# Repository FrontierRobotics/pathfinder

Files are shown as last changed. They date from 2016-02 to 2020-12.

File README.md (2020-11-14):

# Pathfinder

This is the main repository for the Pathfinder Rover. You're in the right spot for over-arching documentation and project tracking. This is also where we keep files and source code central to the design.

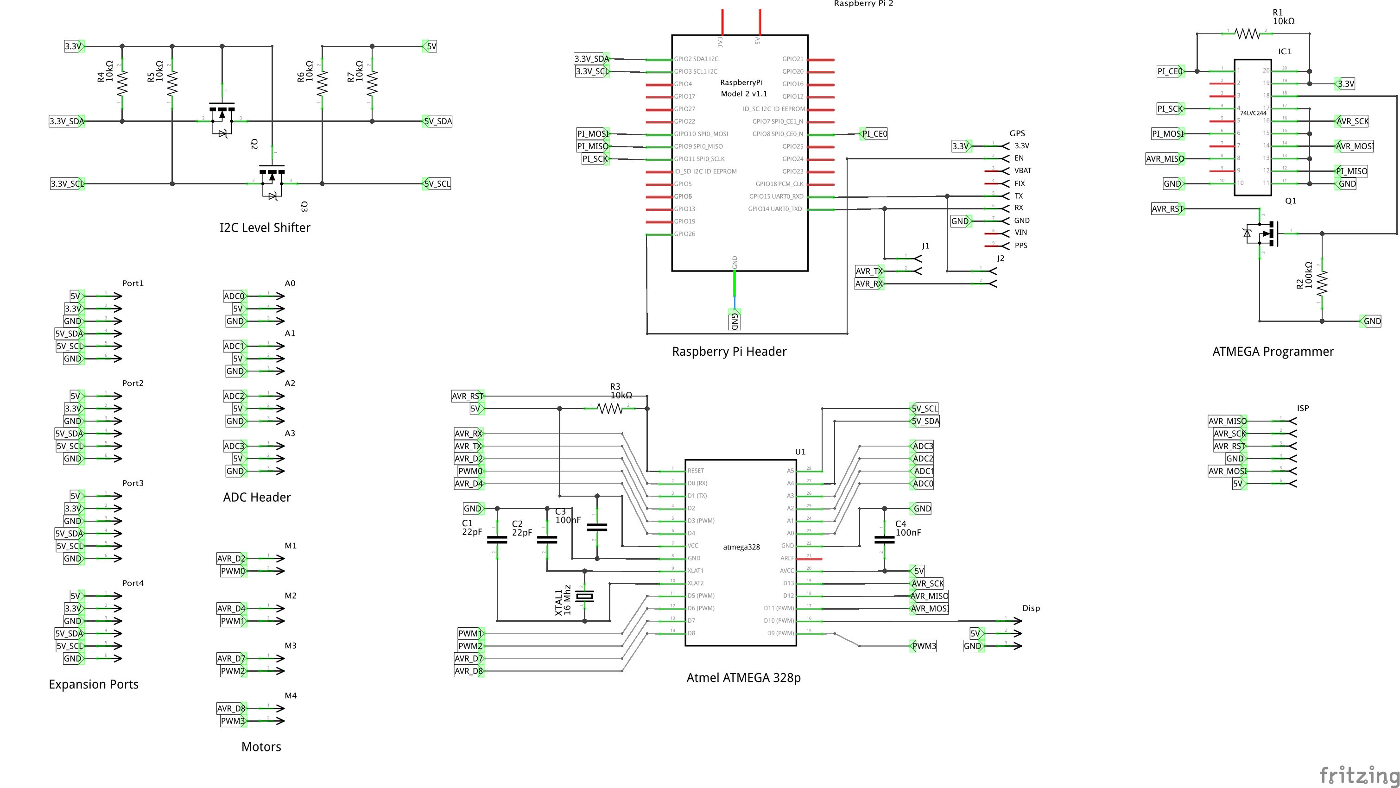
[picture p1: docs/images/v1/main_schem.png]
mainboard


## Roadmap

See our [release roadmap](https://github.com/FrontierRobotics/pathfinder/milestones) to learn about upcoming plans.

## Documentation

Inital Setup:

* [Raspberry Pi Setup](docs/rpi_setup.md)
* [Atmel Programmer Setup](docs/atmel_programmer_setup.md)
* [GPS Setup](docs/gps_setup.md)

Mainboard Circuits:

* [Power Supply](docs/mainboard_power_supply.md)
* [Power Monitor](docs/mainboard_power_monitor.md)

Arduino Code:

* [Protocol](docs/i2c_protocol.md)
* [Development](docs/arduino_build.md)

Raspberry Pi Code:

* [Protocol](docs/i2c_protocol.md)
* [Development](docs/rpi_build.md)

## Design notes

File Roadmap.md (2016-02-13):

# Roadmap

Names: WALL-E, CondonExplorationAdminsration: Pathfinder, Popcorn, Voyager, Snowman, Hubble, CondonExplorationVehichle, TCs, T3R, R2C2

Milestone | Important Considerations
---- | ------------------------
Navigation | Basic chassis, motor control, and obstacle avoidance
Home Waypoints | Position and direction, refined motor control and obstacle avoidance
Park Waypoints | All terrain chassis, advanced motor control and obstacle avoidance
Get to Park | Computer vision and high visibility for traffic avoidance, 
Home Samples | Sampling hardware
Park Samples | Sampling on longer missions
Natural Area Samples | Harsh terrain

## Navigation

* Avoid obstacles (Man Made)
  * Computer vision *(D: 12, P: )*
  * Rangefinding *(D: 5, P: )*
  * LIDAR *(D: W, P: )*
* Direction *(D: 1, P: )*
* Position *(D: 2, P: )*
* Tracking progress on path *(D: 2, P: )*
* Following a known path using waypoints *(D: 5, P: )*
* Motor control *(D: 3, P: )*

## Fail Safe Plan (Recovery)

* Return to known spot *(D: 8, P: )*
* Transmit location *(D: 3, P: )*
* Sticker advertising a fine *(D: 1, P: )*

## Defense

* Plant itself into the earth *(D: 12, P: )*
* Self destruct *(D: 5, P: )*
* Hard armor *(D: 8, P: )*
* Spikes *(D: , P: )*
* Auto-camoflage *(D: , P: )*
* Shock *(D: , P: )*
* Gas (pepper spray or stinky) *(D: , P: )*
* Flashing Lights *(D: , P: )*

## Weather Proofing

* Rain *(D: , P: )*
* Snow *(D: , P: )*

## Harsh Terrain

* Cliffs *(D: , P: )*
* Tall Grass *(D: , P: )*
* Rough Rocks *(D: , P: )*
* Water *(D: , P: )*
  * Puddle *(D: , P: )*
  * Streams *(D: , P: )*
  * Ponds *(D: , P: )*
  * Lakes *(D: , P: )*
  * Rivers *(D: , P: )*
  * Oceans *(D: , P: )*
* Getting stuck
  * Spikes *(D: , P: )*
  * Transmit SOS *(D: , P: )*

## Travel Long Distances

* Energy
  * Solar power *(D: , P: )*
  * Intelligent standby that takes advantage of best sun *(D: , P: )*
  * Large batteries *(D: , P: )*
  * Wind *(D: , P: )*
  * Fuel Cell *(D: , P: )*
* Communication
  * WiFi *(D: , P: )*
  * SatComm *(D: , P: )*
  * Cellular *(D: , P: )*

## Taking Samples

* Dirt samples
  * Claw *(D: , P: )*
  * rotor scoop *(D: , P: )*
* Rock samples
  * Pick up small rocks *(D: , P: )*
  * Drill into large rocks *(D: , P: )*
* Water samples *(D: , P: )*
* Air samples *(D: , P: )*
* Pictures *(D: , P: )*
* Sound *(D: , P: )*
* Audio *(D: , P: )*
* Weather
  * Tempurature *(D: , P: )*
  * Light *(D: , P: )*
  * Pressure *(D: , P: )*
  * Humidity *(D: , P: )*
* Life
  * Snails *(D: , P: )*
  * Plants *(D: , P: )*
  * Microbes *(D: , P: )*
  * Crickets (call them in) *(D: , P: )*
  * Mice *(D: , P: )*

## Sample Analysis

* Spectrometer *(D: , P: )*

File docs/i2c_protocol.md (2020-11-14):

I2C Protocol
============

I2C Device Address: `0x1A`

To initiate an action or send a command to an attached device, the first byte
must be the internal address for that action. Each action has a unique command
sequence described in the sections below.

The general form for sending commands follows:

| Byte 0 | Byte 1  | Following Bytes... |
| --- | --- | --- |
| Internal Address | Command | Command Parameters |

The available actions and their internal address:

| Action  | Internal Addr |
| --- | --- |
| LCD | `0x00` |
| Motor 1 | `0x01` |
| Motor 2 | `0x02` |
| Status  | `0x10` |

LCD
---

**_Not Implemented_** - not necessary, and somewhat unsafe to transmit arbitrary message lengths.

The second byte in the transmission (Byte 1) specifies the command for the LCD.

| Command | Byte 1 | Parameters |
| --- | --- | --- |
| Write | `0x00` | 20 or less bytes to print |
| Set Cursor | `0x01` | byte: row, byte: column |
| Set Brightness | `0x02` | byte: level |
| Clear | `0x02` | None |

Motor
-----

The second byte in the transmission (Byte 1) specifies the command for the
Motor.

| Command | Byte 1 | Parameters |
| --- | --- | --- |
| Forward | `0x00` | byte: speed, `0x00` for stop |
| Reverse | `0x01` | byte: speed, `0x00` for stop |

Status
------

A status message is sent to the master with every interaction. It is possible
to receive a dedicated status message as well.

The form of the status message is a 1 byte value for each sensor.

| | Byte 0 | Byte 1 | Byte 2 |
| --- | --- | --- | --- |
| Sensor | IR 1 | IR 2 | IR 3 |

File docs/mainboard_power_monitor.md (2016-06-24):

# Mainboard Power Monitor

The power monitor for the mainboard is designed with the following features:

* Safe shutdown sequence commands to Raspberry Pi.
* Shutdown interface to mainboard power supply.
* Power quality monitoring and low-voltage protection.
* Health feedback data over I2C.
* Operation mode indicator LED.

## Circuit Overview

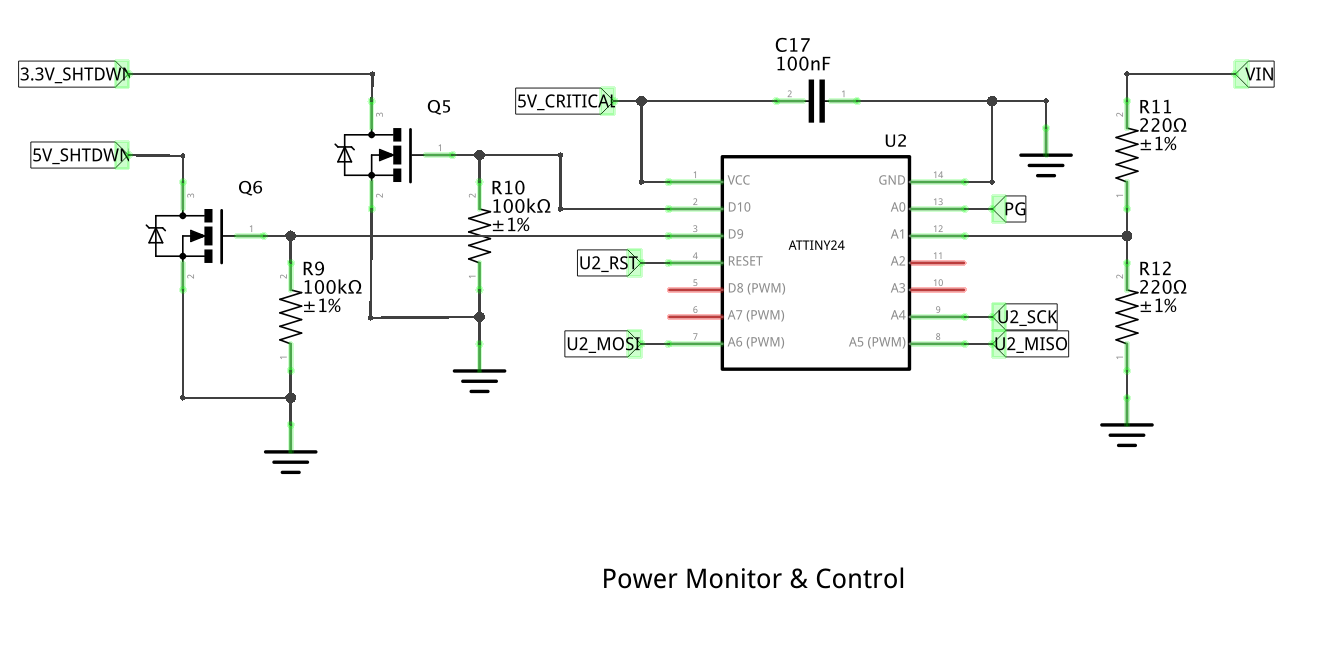
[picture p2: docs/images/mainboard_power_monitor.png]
Circuit Diagram


## Bill of Materials

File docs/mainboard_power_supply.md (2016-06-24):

# Mainboard Power Supply

The power supply for the mainboard is designed with the following features:

* Wide voltage input range of 5.4V to 36V.
* Selectively disabled 2A, 5V and 1A, 3.3V power buses.
* Always-On 1A, 5V critical power bus.

## Circuit Overview

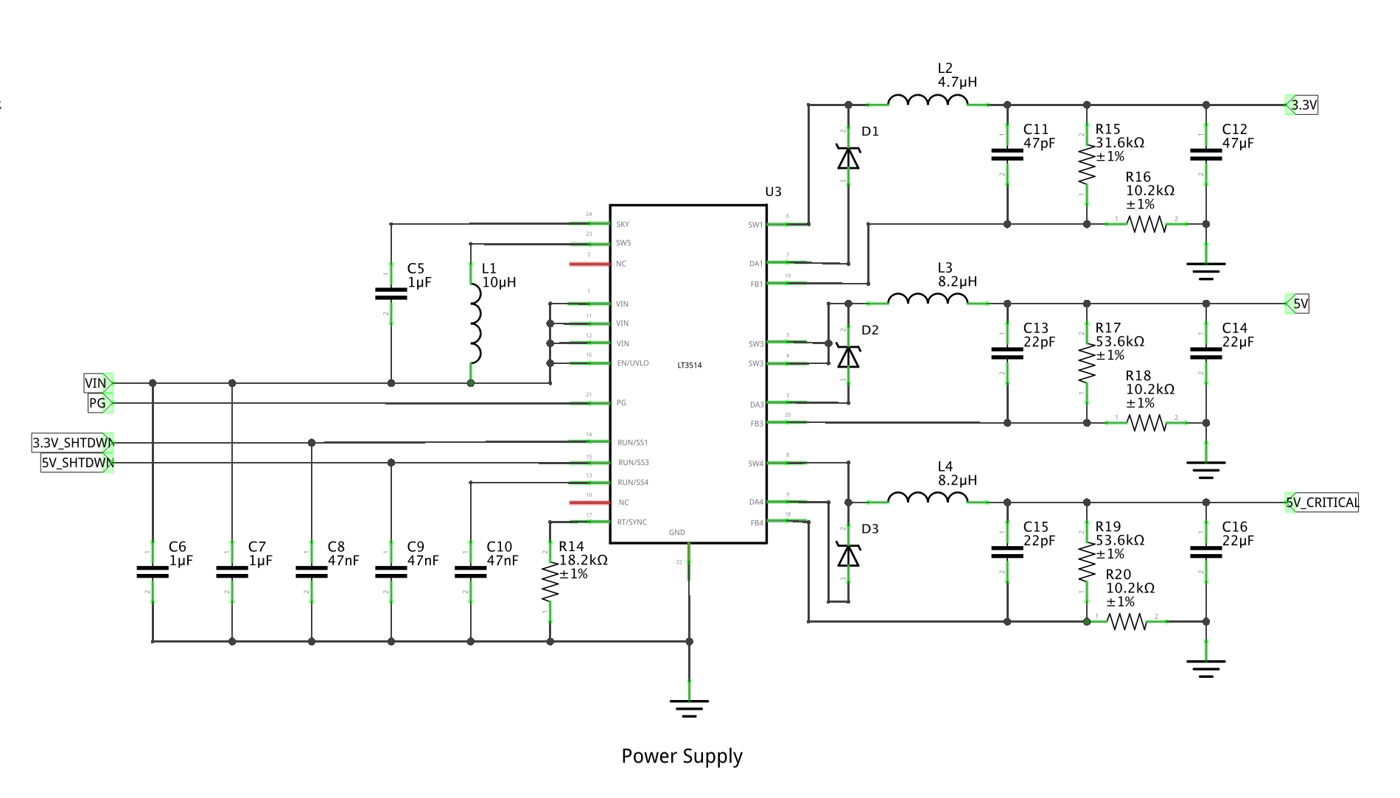
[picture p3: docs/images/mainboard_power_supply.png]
Circuit Diagram


The heart of the power supply is the LT3514 Triple Step-Down Switching Regulator. It consists of three buck regulators with a single 2A channel, and two 1A channels. The device is capable of accepting voltages from 3.2V up to 36V. An on-chip boost regulator allows each channel to operate up to 100% duty cycle, minimizing the need for leveling circuitry.

The LT3514 operates robustly in fault conditions. Cycle-by-cycle peak current limit and catch diode current limit sensing protect the IC, and other mainboard components during overload conditions. Thermal shutdown protects the internal power switches at elevated temperatures. Soft-start helps control the peak inductor current during startup.

The LT3514 features output voltage tracking and sequencing, programmable frequency, programmable undervoltage lockout, and a power good pin to indicate when all ouputs are in regulation.

Channel 3 has the highest current rating, and thus will be used to supply the Raspberry Pi and 5V bus. Channel 1, at 1A, will supply the 3.3V bus. Channel 4 will supply the 5V critical bus for the mainboard power monitor. Channels 1 and 3 will be selectively disabled by the mainboard power monitor circuit during shutdown or low power scenarios. Channel 4 will always be on, supplying the power monitor in standby. By that nature, EN/UVLO will always be enabled as well to ensure constant operation.

## FB Resistor Network

The general formula for the FB resistor network is:

```
R1 = R2 * ((Vout/0.8V) - 1)
```

The datasheet states to use 1% tolerance resisitors, and that a good value for R2 is 10.2kΩ. R2 should not exceed 20kΩ to avoid bias current error.

therefore:

```
Channel 1: 1A, 3.3V
R1 = 10.2kΩ * ((3.3V/0.8V - 1) = 31875Ω ≅ 31.6kΩ

Channel 3: 2A, 5V
R1 = 10.2kΩ * ((5V/0.8V - 1) = 53550Ω ≅ 53.6kΩ

Channel 4: 1A, 5V
R1 = 10.2kΩ * [(5V/0.8V) - 1] = 53550Ω ≅ 53.6kΩ
```
conclusion:

```
R16,18,20 = 10.2kΩ @ ±1%
R15       = 31.6kΩ @ ±1%
R17,19    = 53.6kΩ @ ±1%
```

## Input Voltage Range

The minimum input voltage to regulate the output generally has to be at least 400mV greater than the greatest programmed output voltage. The only exception is when the largest output is less than 2.8V in which case the minimum is 3.2V

The absolute maximum input voltage is 40V, and the LT3514 will regulate so long as the voltage remains less than or equal to that value. However, for constant frequency operation the maximum input voltage is determined through the following formula:

```
VIN(PS) = [(VOUT + VD)/(fSW * tON(MIN)] + VSW - VD
```

where:

* `VIN(PS)` is the maximum input voltage to operate in constant frequency operation without skipping pulses.
* `VOUT` is the programmed output voltage.
* `VSW` is the switch voltage drop, at `IOUT1,4 = 1A`, `VSW1,4 = 0.4V`, at `IOUT3 = 2A`, `VSW3 = 0.4V`.
* `VD` is the catch diode forward voltage drop, for an appropriately sized diode, `VD = 0.4V`.
* `fSW` is the programmed switching frequency. As will be shown in the next section, `fSW = 1.0 MHz`.
* `tON(MIN)` is the minimum on-time, worst-case over temperature = 110ns (at T = 125ºC).

therefore:

```
VIN(PS) = [(5V + 0.4V)/(1.0 MHz * 110ns)] + 0.4V - 0.4V = 49.091V = 40V (device maximum)
VIN(PS) = [(3.3V + 0.4V)/(1.0 MHz * 110ns)] + 0.4V - 0.4V = 40.7V = 40V (device maximum)
```

conclusion:

Our computed `VIN(PS) = 40.7V` exceeds the maximum of 40V, and thus 40V shall be the upper value of VIN. However, the datasheet recommends not starting the LT3514 at input voltages greater than 36V, as the LT3514 must simultaneously conduct maximum currents at high VIN.

Therefore, the recommended input voltage range is `5.4V < VIN < 36V`.

## Frequency Selection

There are two ways to program the frequency:

* Tying a 1% tolerance resistor `RT` from the `RT/SYNC` pin to ground.
* Synchronize the internal oscillator to an external clock.

For our power supply, we'll use the first method. The 1.0 MHz frequency choosen is in the midrange of the LT3514's 250kHz to 2.5MHz operating range. In addition, as shown above, 1.0 MHz results in a full-range `VIN(PS)`. The datasheet includes a table for choosing the proper resistor value for different frequencies.

conclusion:

```
fSW = 1.0 MHz
RT = 18.2kΩ @ ±1%
```

## BOOST Regulator and SKY Pin Considerations

The on-chip boost regulator generates the SKY voltage to be 4.85V above VIN. The SKY voltage is the source of the drive current for the buck regulators that drive the output channels. A good choice for the inductor that will ensure each buck regulator will have sufficient drive current is given by:

```
L = 20.5µH / f
```

where `f` is in MHz. This gives a value of `L = 20.5µH` for `f = 1.0 MHz`.

The optimal SKY pin output current requirement and inductor value is calculated by:

```
ISKY = (IOUT1 * VOUT1 + IOUT3 * VOUT3 + IOUT4 * VOUT4) / 50 * VIN

L = VIN * DC5 / 2 * fSW * [0.3 * (1 - 0.25 * DC5) - ISKY]
```

where:

* `fSW = 1.0 MHz` is the programmed switching frequency.
* `VIN = 12V`, which will be a typical value.
* `DC5 = 0.29412` is the boost regulator duty cycle, given by: `DC5 = 5V/(VIN + 5V)`.
* `VOUT3,4 = 5V`, `VOUT1 = 3.3V`, `IOUT1,4 = 1A`, `IOUT3 = 2A`

therefore:

```
ISKY = (1A * 3.3V + 2A * 5V + 1A * 5V) / 50 * 12
ISKY = 18.3 / 600 = 30.5mA

L = 12V * 0.29412 / 2 * 1.0 MHz * [0.3 * (1 - 0.25 * 0.29412) - 30.5mA]
L = 3.52944 / 2000000 * (0.3 * 0.92647 - 0.0305)
L = 3.52944 / 2000000 * 0.247441 = 0.00000713188194H
L ≅ 7.1µH
```

From the example in the datasheet using different output voltages, we calculated this optimal value of L:

```
ISKY = 13.4 / 600 = 22.3mA
L ≅ 6.9µH
```

This is very close to our computed value. The value of L chosen for the example is 10µH. We will also use this value for our design.

conclusion:

The chosen value of the inductor is 10µH for `VIN = 12V`.

## Inductor Selection

```
L = 2 * (VOUT + VD)/fSW for Channels 1, 4
L = (VOUT + VD)/fSW for Channel 3
```

## Bill of Materials

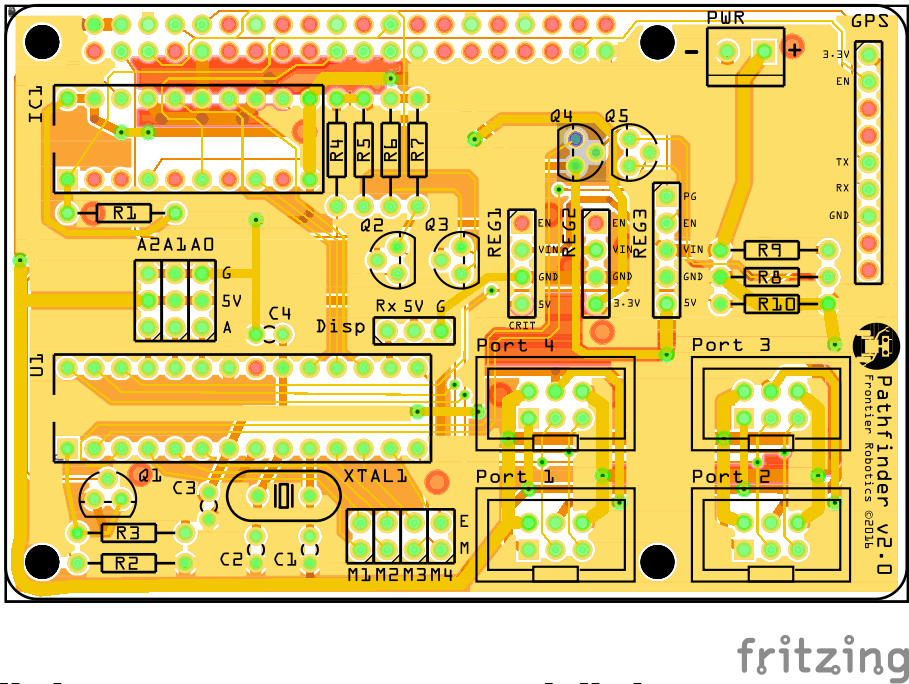
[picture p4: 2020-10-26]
docs/images/v2/main_pcb.png

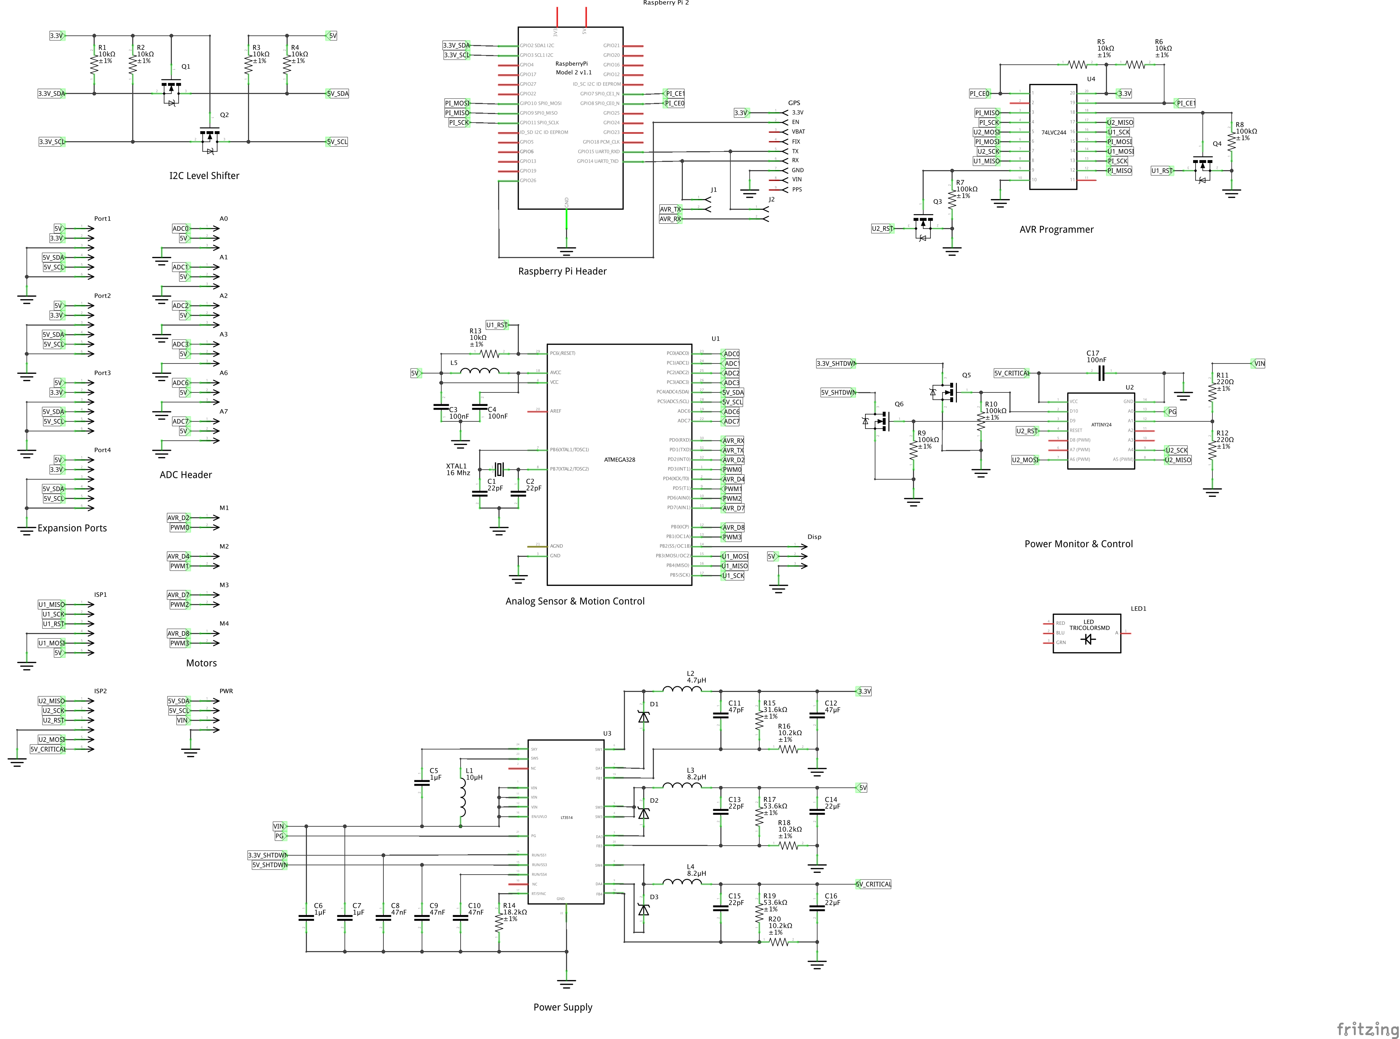
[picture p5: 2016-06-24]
docs/images/mainboard.png

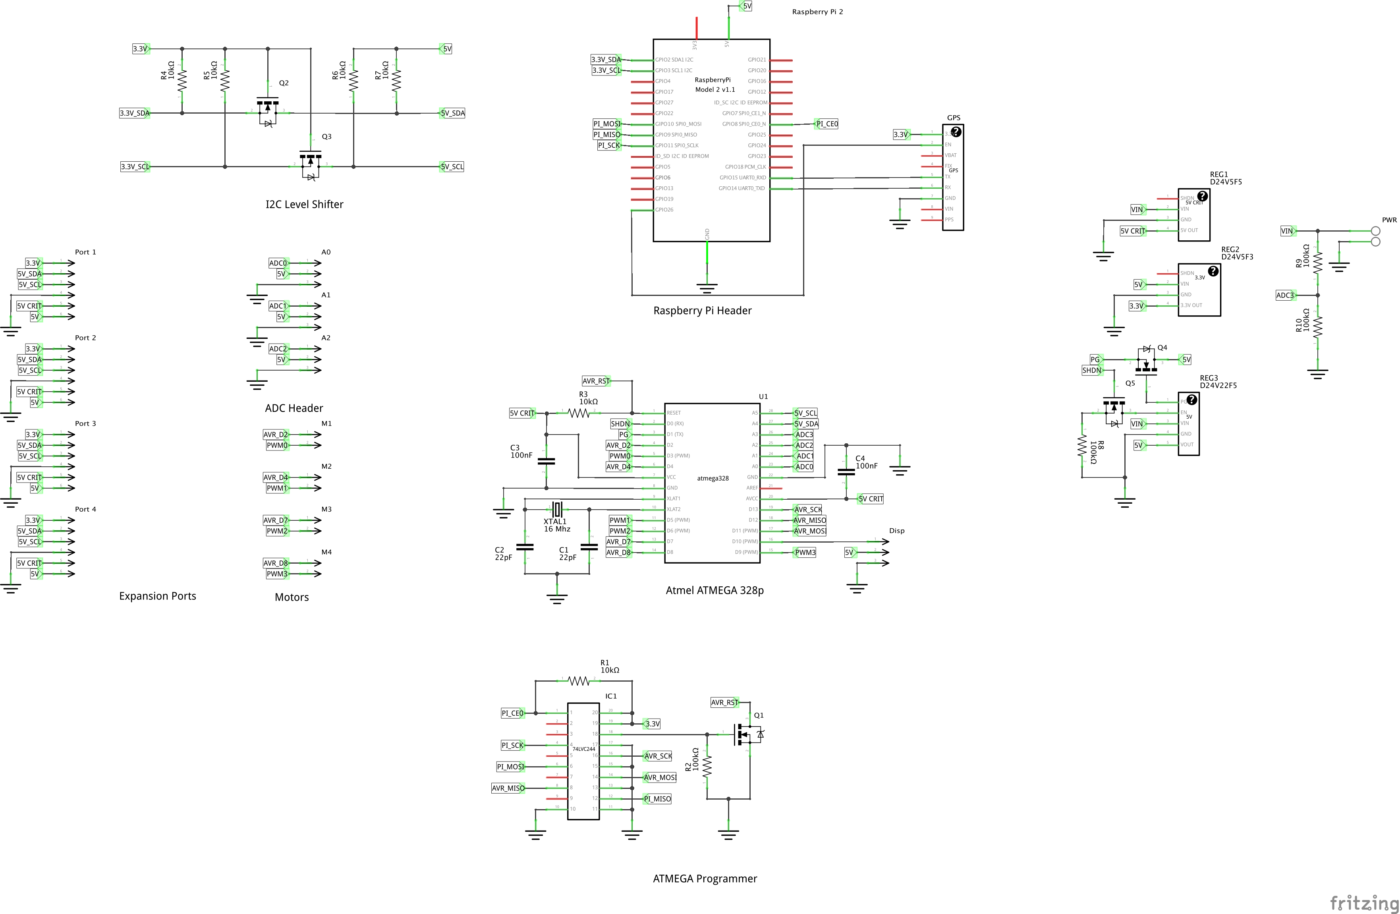
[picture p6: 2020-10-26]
docs/images/v2/main_schem.png

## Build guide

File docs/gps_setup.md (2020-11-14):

# GPS Setup

Pathfinder uses the [Ultimate GPS module from Adafruit](https://www.adafruit.com/product/746).

## Stealing back the serial port from the console

In addition to enabling the serial port like we did in [Raspberry Pi Setup](rpi_setup.md), we also have to take it away from the console service.

```
sudo systemctl stop serial-getty@ttyS0.service
sudo systemctl disable serial-getty@ttyS0.service
```

You also need to remove the console from the cmdline.txt. If you edit this with:

```
sudo nano /boot/cmdline.txt
```

You will see something like:

```
dwc_otg.lpm_enable=0 console=serial0,115200 console=tty1 root=/dev/mmcblk0p2 rootfstype=ext4 elevator=deadline fsck.repair=yes root wait
```

Remove the part mapping the console to serial0:

```
console=serial0,115200
```

Save and reboot for changes to take effect.

## Observing the output

The Ultimate GPS module runs at 9600 baud 8N1.

### Minicom

If this is your thing, first start it up in setup mode:

```
sudo minicom -s
```

Put in the proper device, `/dev/ttyS0` and the baud rate, then start it up like normal:

```
sudo minicom
```

### Screen

This is probably the easiest.

```
sudo screen /dev/ttyS0 9600
```

That's it! [See the rest of the documentation to continue.](../README.md)

----

* [Using UART](https://learn.adafruit.com/adafruit-ultimate-gps-on-the-raspberry-pi/using-uart-instead-of-usb)
* [Configuring GPIO Serial](http://spellfoundry.com/2016/05/29/configuring-gpio-serial-port-raspbian-jessie-including-pi-3)

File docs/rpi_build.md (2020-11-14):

Raspberry Pi Build
==================

Cross Compiling
---------------

Change directories to where `main.go` resides and run `go build` with environment variables for the target platform:
```
$ cd cmd/pathfinder
$ env GOOS=linux GOARCH=arm GOARM=5 go build
```

Send the compiled binary to the Raspberry Pi:
```
$ scp pathfinder pi@192.168.3.147:/home/pi
```

Executing
---------

First make sure the Arduino code is [built and flashed](arduino_build.md).

On the Raspberry Pi:

Run the executable to start upPathfinder:

```
$ ./pathfinder
```

Or, to test the I2C commands directly...

Make both motors go forward at 50%:
```
$ ./test-i2c 010180 // Motor 1
$ ./test-i2c 020180 // Motor 2
```

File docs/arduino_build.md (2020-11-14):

Arduino Build
=============

Wiring
------

**NOTE!** When connecting and referencing pins, use the Arduino pin number! For example, use pin 2 a.k.a D2 in code
instead of physical pin 4.

Compilation
-----------

From the root of this repository, open [Main.ino](../arduino/Main/Main.ino)

Click the Arduino/Verify button at the top right. (Opt+Cmd+R)

The output of the compilation goes into the [build directory](../arduino/Main/build)(ignored in Git). Inside this directory you'll find two `.hex` files, with and without the bootloader. We can use usually the one without the bootloader because it's already in flash.

Send the compiled `.hex` to the Raspberry pi for flashing:
```
$ scp Main.ino.hex pi@192.168.3.147:/home/pi
```
On the Raspberry Pi:

Flash the `.hex` file:
```
sudo avrdude -P gpio -c gpio -p atmega328p -U flash:w:Main.ino.hex
```

That's it for updating the Arduino firmware. From here the Raspberry Pi code can be executed to communicate with the Arduino over I2C.

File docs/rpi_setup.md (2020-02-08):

# Raspberry Pi Setup

## Load the Image

1. Download the latest [Raspbian Jessie with Pixel image](https://downloads.raspberrypi.org/raspbian_latest).
2. Use [Etcher](https://etcher.io/) to burn the image onto the SD card.

Once you've got the image loaded hook up a keyboard, mouse, TV via HDMI, and USB power supply. Then power it up!

## Set up WiFi

### Step 1: Give yourself administrative access:

```
sudo su
```

### Step 3: Identify your network adapter and SSID:

Note: Take note of the line with 802.11 on it and what comes to the left of it. This is your wireless card and you'll need it in the steps that follow.

```
iwconfig
```

The output of this command will look something like the following:

```
eth0 no wireless extensions.

wlan0 IEEE 802.11bgn ESSID:off/any
Mode:Managed Access Point: Not-Associated Tx-Power=20 dBm
Retry short limit:7 RTS thr:off Fragment thr:off
Power Management:off

lo no wireless extensions.
```

Run the following command to make sure your SSID is visible to the interface:

```
sudo iwlist wlan0 scan | grep "ESSID"
```

### Step 4: Stop Network Manager if it is running:

```
service network-manager stop
```

### Step 5: Create a wpa_supplicant.conf file by replacing access_point_name with your SSID:

To avoid storing your password in plain text, run the following command

```
wpa_passphrase "access_point_name" > /etc/wpa_supplicant/wpa_supplicant_temp.conf
```

Note: The prompt you'd normally get is eaten by the redirection to the file. Just type your password and everything will be ok.

Copy the content of what that produced at the bottom of `/etc/wpa_supplicant/wpa_supplicant_temp.conf`. You'll want to remove your commented-out plain text password.

TODO Paste in example

### Step 6: Set up the network interface file:

```
nano /etc/network/interfaces
```

Edit the existing interface, or set up a new one at the bottom of the file (if your wireless adapter does not show up as wlan0 replace it with what did show up when running iwconfig above) to get an IP address automatically via your DHCP/router/access point:

```
auto wlan0
iface wlan0 inet dhcp
wpa-conf /etc/wpa_supplicant/wpa_supplicant.conf
```

### Step 7: Activate the wireless connection:

```
ifdown wlan0 && ifup wlan0
```

Sometimes it fails on the first try. Give it another go before banging your head too hard.

## Configuration

Turn on the appropriate settings depending on what you'll need. Don't turn on stuff you won't use, it'll just take more energy. Once finished click OK. It'll probably want to reboot.

Go into Start->Preferences->Raspberry Pi Configuration

### System

Set Password to: <Your Password> (default is raspberry)

Set Hostname to: pathfinder

### Interfaces

Turn on SSH, SPI, I2C, Serial.

### Performance

Nothing to change.

### Localisation

Set Locale to:

* Language: en (English)
* Country: US (USA)
* Character Set: UTF-8

Set Timezone to:

* Area: Etc
* Location: UTC

Set Keyboard to: United States, English (US)

Set WiFi Country Code to: US United States

## Get the IP and log in remotely

First find your Raspberry Pi's IP address running the following command:

```
ifconfig
```

Or use `nmap` to find it on the network:

```
nmap -sn 192.168.1.0/24

Starting Nmap 7.40 ( https://nmap.org ) at 2017-02-24 17:42 MST
.
.
Nmap scan report for pathfinder (192.168.1.16)
Host is up (0.038s latency).
.
.
Nmap done: 256 IP addresses (9 hosts up) scanned in 2.41 seconds
```

Once you've got the IP, log in through ssh:

```
ssh pi@192.168.1.16
```

## Upgrade and customize the OS

Run `sudo apt-get update` and `sudo apt-get upgrade` to get the system up-to-date.

Install the following packages:

```
sudo apt-get install vim screen minicom
```

Then edit `~/.bashrc` and uncomment the following lines:

```
# some more ls aliases
alias ll='ls -l'
alias la='ls -A'
alias l='ls -CF'
```

That's it! [See the rest of the documentation to continue.](../README.md)

----

### References

* [ThinkPenguin.com - Wireless CLI](https://www.thinkpenguin.com/gnu-linux/how-configure-wifi-card-using-command-line-or-terminal)
* [RaspberryPi.org - Wireless CLI](https://www.raspberrypi.org/documentation/configuration/wireless/wireless-cli.md)
* [RaspberryPi.org - IP Address](https://www.raspberrypi.org/documentation/remote-access/ip-address.md)

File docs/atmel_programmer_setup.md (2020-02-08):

# Atmel Programmer Setup

Steve Marple designed an implementation of a AVR ISP programmer using the Raspberry Pi GPIO port which can be used to program Atmel's AVR range of microcontrollers with avrdude. An ISP programmer based on this design was incorporated into the Pathfinder mainboard. Mr. Marple usThis post explains how to use avrdude to actually program devices.

## Software installation
Use `scp` to upload the [patched version of avrdude](../avrdude) onto the Pi. You will probably want the armhf (hardware floating-point) version. Upload the documentation package for avrdude too. Install the packages using `dpkg -i`. For example:

```
sudo dpkg -i avrdude_5.10-4_armhf.deb
sudo dpkg -i avrdude-doc_5.10-4_all.deb
```

Using avrdude over the GPIO interface is problematic for users other than root. The easiest solution is to give the avrdude binary setgroup permission:

```
sudo chmod g+s /usr/bin/avrdude
```

## Usage

Selecting the GPIO programmer is simply a matter of including `-P gpio -c gpio` options; the `-P` option specifies that the GPIO port is used (as opposed to USB, serial or parallel interfaces) whilst the `-c` option selects the correct programmer type on that port.

For example, to check the signature on an ATmega328P execute the command:

```
sudo avrdude -P gpio -c gpio -p atmega328p
```

To read the fuses execute the command:

```
sudo avrdude -P gpio -c gpio -p atmega328p -U lfuse:r:-:h -U hfuse:r:-:h -U efuse:r:-:h
```

To flash the device:

```
sudo avrdude -P gpio -c gpio -p atmega328p -U flash:w:Motion.ino.standard.hex
```
To read the device's flash:

```
sudo avrdude -P gpio -c gpio -p atmega328p -U flash:r:backup.hex:r
```

## Customization

The packages above define a single programmer called gpio which uses the gpio interface on GPIO pins 8 to 11. If expanding the mainboard to implement two independent programmers, use gpio0 and gpio1. You can add these by creating a `.avrduderc` file in your home directory. The file should contain:

```
programmer
  id    = "gpio0";
  desc  = "Use sysfs interface to bitbang GPIO lines";
  type  = gpio;
  reset = 8;
  sck   = 11;
  mosi  = 10;
  miso  = 9;
;

programmer
  id    = "gpio1";
  desc  = "Use sysfs interface to bitbang GPIO lines";
  type  = gpio;
  reset = 7;
  sck   = 11;
  mosi  = 10;
  miso  = 9;
;
```

That's it! [See the rest of the documentation to continue.](../README.md)

----

### References

* [Steve Marple - ISP Design](http://blog.stevemarple.co.uk/2012/07/avrarduino-isp-programmer-using.html)
* [Steve Marple - How to Use](http://blog.stevemarple.co.uk/2013/03/how-to-use-gpio-version-of-avrdude-on.html)
* [Steve Marple - RPi_RFM12B_ISPd](https://github.com/stevemarple/RPi_RFM12B_ISP/tree/master/software/avrdude)
* [Sparkfun](https://learn.sparkfun.com/tutorials/pocket-avr-programmer-hookup-guide/using-avrdude)

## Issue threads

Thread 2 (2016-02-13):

Can control motors on a basic chassis.

andycondon, 2016-02-13:
- [ ] Drive forward
- [ ] Reverse
- [ ] Turn sharp left
- [ ] Turn sharp right
- [ ] Bank left
- [ ] Bank right
- [ ] About face

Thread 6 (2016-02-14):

Has a printed circuit board for navigation components.

tylercondon, 2016-02-14:
- [x] Connections for power
- [x] Connections for Raspberry Pi 2
- [x] Circuit for ATMega 328p
- [x] Circuit for Raspi to ATMega programmer
- [x] Connection for GPS module
- [x] Connections for IR range finders
- [x] Connections for motor control
- [x] Connection for ISP

andycondon, 2017-01-27:
Done! Actually this was done like a year ago.

Closed 2017-01-27.

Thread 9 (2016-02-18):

Has a printed circuit board for energy components.

andycondon, 2016-02-18:
- [ ] Input connection for 6V electronics battery.
- [ ] Input connection for 12V motion battery.
- [ ] Output connection for regulated 5V 2A USB power.
- [ ] Output connection for regulated 5V 1A power.
- [ ] Output connection for regulated 3.3V 500mA power.
- [ ] Output connection for unregulated 12V power.
- [ ] Battery levels available through I2C communication.
- [ ] Battery temperature available through I2C communication.
- [ ] USB power can be turned on/off through I2C communication.

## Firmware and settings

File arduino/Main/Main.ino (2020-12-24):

#include <Wire.h>
#include <RingBufCPP.h>
#include "Motor.h"

#define I2C_ADDRESS 0x1A
#define I2C_BUFFER_SIZE 32
#define MAX_NUM_ELEMENTS 30
#define IR_ADDRESS 0x10
#define MOTOR1_ADDRESS 0x01
#define MOTOR2_ADDRESS 0x02

char i2c_buffer[I2C_BUFFER_SIZE];
volatile byte internal_address;

struct Event
{
  byte internal_address;
  byte direction;
  byte speed;
};

// Remember to use Arduino pins, not physical ones
Motor motor1 = Motor(2, 3);
Motor motor2 = Motor(4, 5);
RingBufCPP<struct Event, MAX_NUM_ELEMENTS> buf;

void setup()
{
  motor1.begin();
  motor2.begin();
  Wire.begin(I2C_ADDRESS);
  Wire.onReceive(receiveEvent);
  Wire.onRequest(requestEvent);
}

void loop()
{
  struct Event e;

  while (buf.pull(&e))
  {
    switch (e.internal_address)
    {
    case MOTOR1_ADDRESS:
      motor_event(&motor1, e.direction, e.speed);
      break;
    case MOTOR2_ADDRESS:
      motor_event(&motor2, e.direction, e.speed);
      break;
    }
  }

  delay(2000);
}

void requestEvent()
{
  switch (internal_address)
  {
  case IR_ADDRESS:
    byte sensor_left = analogRead(A0);
    byte sensor_front = analogRead(A1);
    byte sensor_right = analogRead(A2);
    Wire.write(sensor_left);
    Wire.write(sensor_front);
    Wire.write(sensor_right);
    break;
  }
}

void receiveEvent(int receive_size)
{
  if (!Wire.available())
  {
    internal_address = 0x00;
    return;
  }
  internal_address = Wire.read();

  if (internal_address == MOTOR1_ADDRESS || internal_address == MOTOR2_ADDRESS)
  {
    if (!Wire.available())
    {
      return;
    }
    byte direction = Wire.read();

    if (!Wire.available())
    {
      return;
    }
    byte speed = Wire.read();

    struct Event e;
    e.internal_address = internal_address;
    e.direction = direction;
    e.speed = speed;
    buf.add(e);
  }
}

void motor_event(Motor *motor, byte direction, byte speed)
{
  if (0x01 == direction)
  {
    motor->forward(speed);
  }
  else
  {
    motor->reverse(speed);
  }
}

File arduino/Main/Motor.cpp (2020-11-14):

#include <Arduino.h>
#include "Motor.h"

Motor::Motor(int dPin, int pwmPin) : _dPin(dPin), _pwmPin(pwmPin), _speed(0), _reversed(false)
{
    pinMode(dPin, OUTPUT);
}

void Motor::begin()
{
    forward(0x00);
}

void Motor::forward(byte speed)
{
    _reversed = false;
    _speed = speed;
    digitalWrite(_dPin, LOW);
    analogWrite(_pwmPin, speed);
}

void Motor::reverse(byte speed)
{
    _reversed = true;
    _speed = speed;
    digitalWrite(_dPin, HIGH);
    analogWrite(_pwmPin, speed);
}

bool Motor::isReversed()
{
    return _reversed;
}

bool Motor::isStopped()
{
    return 0x00 == _speed;
}

byte Motor::speed()
{
    return _speed;
}

const char *Motor::status()
{
    if (isStopped())
    {
        return "STOP";
    }
    char *result = (char *)malloc(sizeof(char) * 4);
    if (isReversed())
    {
        sprintf(result, "R%03d", speed());
    }
    else
    {
        sprintf(result, "F%03d", speed());
    }
    return result;
}

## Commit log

2016-02-14 Just getting started.
    [navigator.fzz]
2016-02-14 Adding in more parts.
    [navigator.fzz]
2016-02-14 Swapped out GPS module
    It was too ugly having it out of scale in the schematic.
    [navigator.fzz]
2016-02-14 Decided to use Raspi 3.3V
    [navigator.fzz]
2016-02-14 Decided against powering navigation from Pi.
    [navigator.fzz]
2016-02-14 Connecting power.
    [navigator.fzz]
2016-02-14 Working on the AVR programmer.
    [navigator.fzz]
2016-02-15 More progress on the AVR programmer.
    [navigator.fzz]
2016-02-15 Should now be a match for my breadboard.
    [navigator.fzz]
2016-02-18 Just a little rename.
    [navigation.fzz]
2016-02-19 Major overhaul using net labels. This is so much easier!
    [navigation.fzz]
2016-02-19 Just naming things.
    [navigation.fzz]
2016-02-20 Lining up components on PCB.
    [navigation.fzz]
2016-02-20 Initial components layout.
    [navigation.fzz]
2016-02-20 Power bus is done.
    [navigation.fzz]
2016-02-21 Made ports universal and added one.
    [navigation.fzz]
2016-02-22 More I2C progress.
    [navigation.fzz]
2016-02-22 Getting ready to unblock myself.
    [navigation.fzz]
2016-02-22 Unblocked again.
    [navigation.fzz]
2016-02-23 Removed an expansion port to make way for IR rangefinders.
    [navigation.fzz]
2016-02-24 Moving motor connections together.
    [navigation.fzz]
2016-02-24 Motors are done.
    [navigation.fzz]
2016-02-25 Working out I2C.
    [navigation.fzz]
2016-02-26 Adding in ISP header.
    [navigation.fzz]
2016-02-26 Less vias, more lines.
    [navigation.fzz]
2016-02-26 Optimized I2C connections.
    [navigation.fzz]
2016-02-26 More optimizations.
    [navigation.fzz]
2016-02-26 ISP exposed.
    [navigation.fzz]
2016-02-27 Adding in a spot for the arduino code.
2016-02-27 Added another ADC header.
    [main.fzz]
2016-02-27 Connect serial line for GPS to AVR with jumpers.
    [main.fzz]
2016-02-27 Ran the serial lines.
    [main.fzz]
2016-02-27 Trying to pick apart the data lines.
    [main.fzz]
2016-02-27 Almost there.
    [main.fzz]
2016-02-27 It says routing completed!
    [main.fzz]
2016-02-27 Optimizations and bug fixes.
    [main.fzz]
2016-02-27 More optimizations and silkscreening.
    [main.fzz]
2016-02-27 Final touches.
    [main.fzz]
2016-02-27 More tweaks.
    [main.fzz]
2016-02-27 Ground fill!
    [main.fzz]
2016-02-27 Groundplane cleanup.
    [main.fzz]
2016-02-28 Silkscreen tweaks. GPS enable.
    [main.fzz]
2016-02-28 I think it's done.
    [main.fzz]
2016-02-28 Slight tweaks.
    [main.fzz]
2016-04-07 Version 2 will use mostly surface mount stuff.
    [main.fzz]
2016-04-07 More components as SMD. Choosing 1/8W ±1% resistors.
    [main.fzz]
2016-04-09 Adding a custom part for the LT3514.
    [main.fzz]
2016-04-09 Using latest iteration of LT3514.
    [main.fzz]
2016-04-09 Starting to arrange the smaller parts.
    [main.fzz]
2016-04-13 Making a little progress on the power supply and started using the correct symbol for ground.
    [main.fzz]
2016-04-13 3.3V branch complete.
    [main.fzz]
2016-04-14 Got the basics down for the power supply.
    [main.fzz]
2016-04-14 A little cleanup.
    [main.fzz]
2016-04-15 Creating shutdown circuits.
    [main.fzz]
2016-04-16 Moar progress on the power control circuit.
    [main.fzz]
2016-04-16 Making the programmer for second AVR.
    [main.fzz]
2016-04-16 AVR Programmer is done.
    [main.fzz]
2016-04-16 Starting to build the ISP header.
    [main.fzz]
2016-04-16 Better idea for ISP.
    [main.fzz]
2016-04-17 Swap ATMega328 PDIP for TQFP
    [main.fzz]
2016-04-17 Sorted component names.
    [main.fzz]
2016-04-17 Capturing requirements for the power supply.
2016-04-17 Stating which channels will be used for which power buses.
2016-04-18 Calculated FB resistor network values.
2016-04-18 Starting to compute optimal input voltage range.
2016-04-26 Writeup for input voltage range.
2016-04-27 Refactoring power supply documentation.
2016-04-27 Working out the inductor value for the boost regulator.
2016-04-30 Finished Boost Regulator inductor section.
2016-05-03 Replaced GND net label with ground symbol.
    [main.fzz]
2016-05-03 Cleaned up schematic and gave 5V to Pi.
    [main.fzz]
2016-05-04 Bug fixes.
    [main.fzz]
2016-05-04 Adding icon.
    [main.fzz]
2016-05-05 Ground fill.
    [main.fzz]
2016-06-15 Fixing the 2n7000 pinout.
    [main.fzz]
2016-06-15 2 of 3 2n7000 replaced.
    [main.fzz]
2016-06-17 Swapped out transistor and GPS parts.
    [main.fzz]
2016-06-17 Getting power circuit designed.
    [main.fzz]
2016-06-21 Power supply progress.
    [main.fzz]
2016-06-21 Almost routed.
    [main.fzz]
2016-06-21 Just gotta fix the GPS data lines.
    [main.fzz]
2016-06-21 Just gotta tie in 3.3V and GND.
    [main.fzz]
2016-06-22 Fixed a bug.
    [main.fzz]
2016-06-22 AVCC needed 5V critical.
    [main.fzz]
2016-06-23 Expansion ports now compatible with Raspberry Pi.
    [main.fzz]
2016-06-24 Silkscreen polish.
    [main.fzz]
2016-10-04 A couple more methods.
2016-10-05 Just print out the characters.
2016-10-14 Rounting commands to the LCD.
    Uses the internal address to determine it the command if for the LCD. Uses a 32 byte command buffer. Safely reads the data off I2C.
    Also, got rid of some LCD functions we won't use here. They'll be left to callers upstream to figure out.
    [LCD.cpp]
2017-02-24 Link to Raspberry Pi Setup.
2017-02-25 Adding a couple links.
2020-10-26 Implement I2C protocol. Use VS Code.
2020-11-02 Implement IR sensors. Remove LCD commands.
2020-11-14 Restructure Arduino code
2020-11-15 Refactor status, remove 'arduino' abstraction
2020-11-16 Add motor and driver
2020-11-20 Fix bugs due to LCD printing in I2C handlers
    [Main.ino]
2020-11-22 Wire up channels for sensors and commands
2020-12-20 Use errgroup to cleanup main and improve error handling
    These seem somewhat common: `sysfs-i2c: remote I/O error`.
    Slowing i2c polling to see if they diminish. We can also log them and move on if they're transient.
2020-12-22 Use a ring buffer between the interrupt and main loop
2020-12-22 Cut out the software-serial based LCD :-(
    It causes crashes. I've ordered an I2C / serial based backpack so we can still have a display. This will free up the AVR for sensors, motors, startup/shutdown, and other critical low-power functions.
    [Main.ino]
2020-12-22 Only send the motor command if it's different
2021-01-04 Integrate BNO-055 orientation sensor
